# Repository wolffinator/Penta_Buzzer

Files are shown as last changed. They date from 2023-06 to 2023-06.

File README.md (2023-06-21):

# Penta Buzzer
A buzz for the fingers.  
Open source code and assembly for a mobile 4 buzzer hand thingy.  
Purpose of this device is to provide a pre-programmed buzzing pattern to each of the 4 fingers.  
## 💡 Current Features
* Runs program to buzz each finger at set intervals.
* Battery life of over 4hrs while running.
* On/Off button.
* Charge port that also doubles as programming port.
## ⚠️ Word of Warning
* This project is at its infancy. The current hardware design will change and may not work with future versions of this code.
* Project requires intermediate skills in soldering. There are a few surface mount soldering points and many close solder pads. Practice technique if you are unsure.
* ESP32 does not have reverse polarity protection (ask me how I know). Check your work before you fry your board.
* This is not a well designed product (yet). Parts will and have failed. 
### BOM
* [Seeed Studio XIAO ESP32-C3][esp32_c3_link]. This is the microcontroller used in this project. This was chosen due to its built in connectivity and battery management circuitry.  
* [DRV 8833][drv_8833_link]. This is the motor controller which will power each of the 4 buzzers.  
* [MakerFocus 2A 5V Charging Protection Module][makerfocus_charge_discharge_module_link]. This is used to provide 5v for the motors and show current battery capacity. The charging of the battery is accomplished by the microcontroller circuit.
* [9 by 20 by 30mm lithium ion battery][lithium_ion_battery_link] 
* Heat Shrink
* 30AWG stranded wire.
* 22AWG solid core wire.
### 3d Printable Case
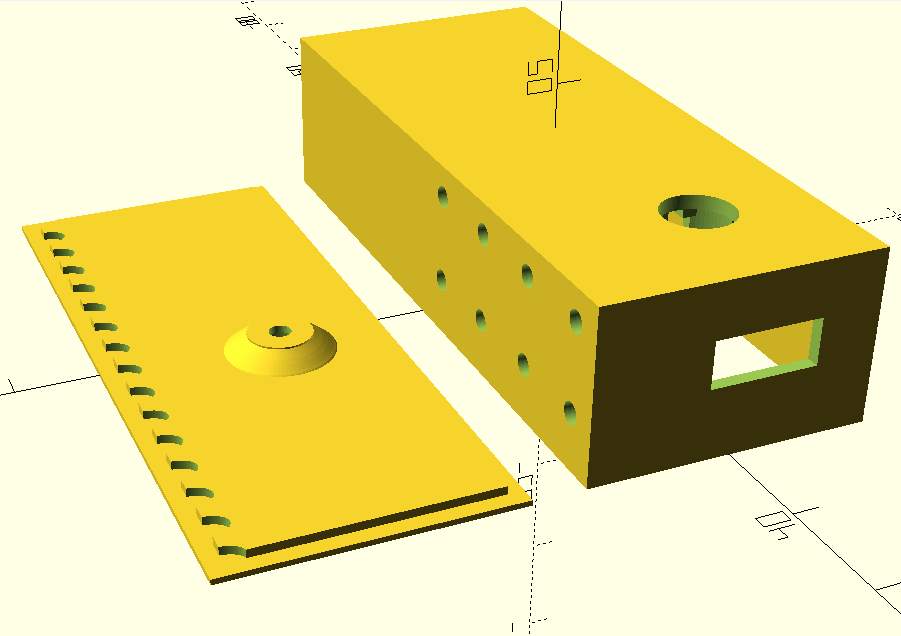
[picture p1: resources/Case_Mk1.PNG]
3d Printable Case

There is an OpenScad document in the Models directory that can be 3d printed as an enclosure for the whole setup. I plan to rework this as it was a pain to assemble.
## 🛠 Flash Firmware (For Users)

## 🛠 Installation Setup (For Developers)
### Install Arduino IDE
### Install Board Support Packages for ESP32
### Install Visual Studio Code (VS-Code)

### Install Platform IO Extension for VS-Code

### Flash Board Firmware

## 🔬 Future plans
### Version 2
* Goal of Version 2 is to see if I can create a PCB that works, is small, and combines many boards into a small footprint.
* Explore fabrication proccess
* Additional goal is for me (wolffinator) to get better at SMD soldering since this will most likely require some rework/repair.
### Version 2 Progress:
#### Schematic
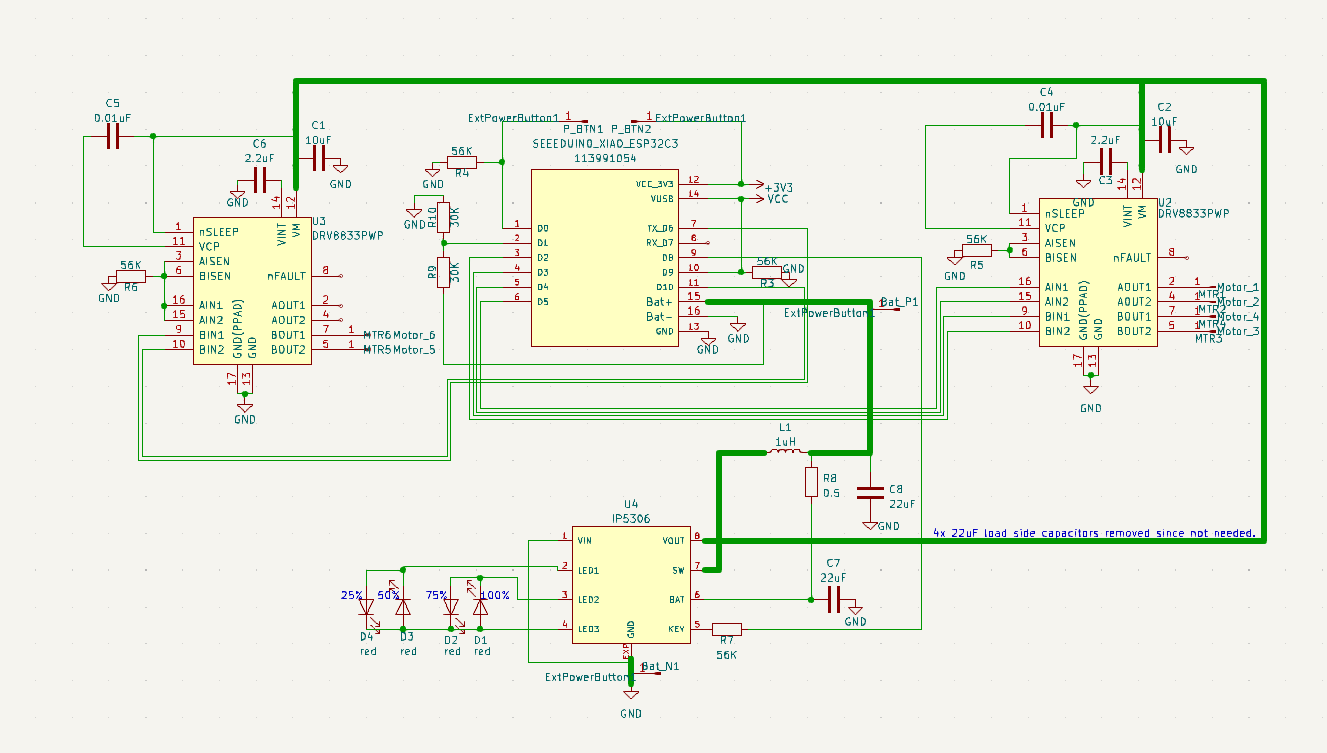
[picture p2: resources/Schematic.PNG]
Schematic

#### PCB Layout
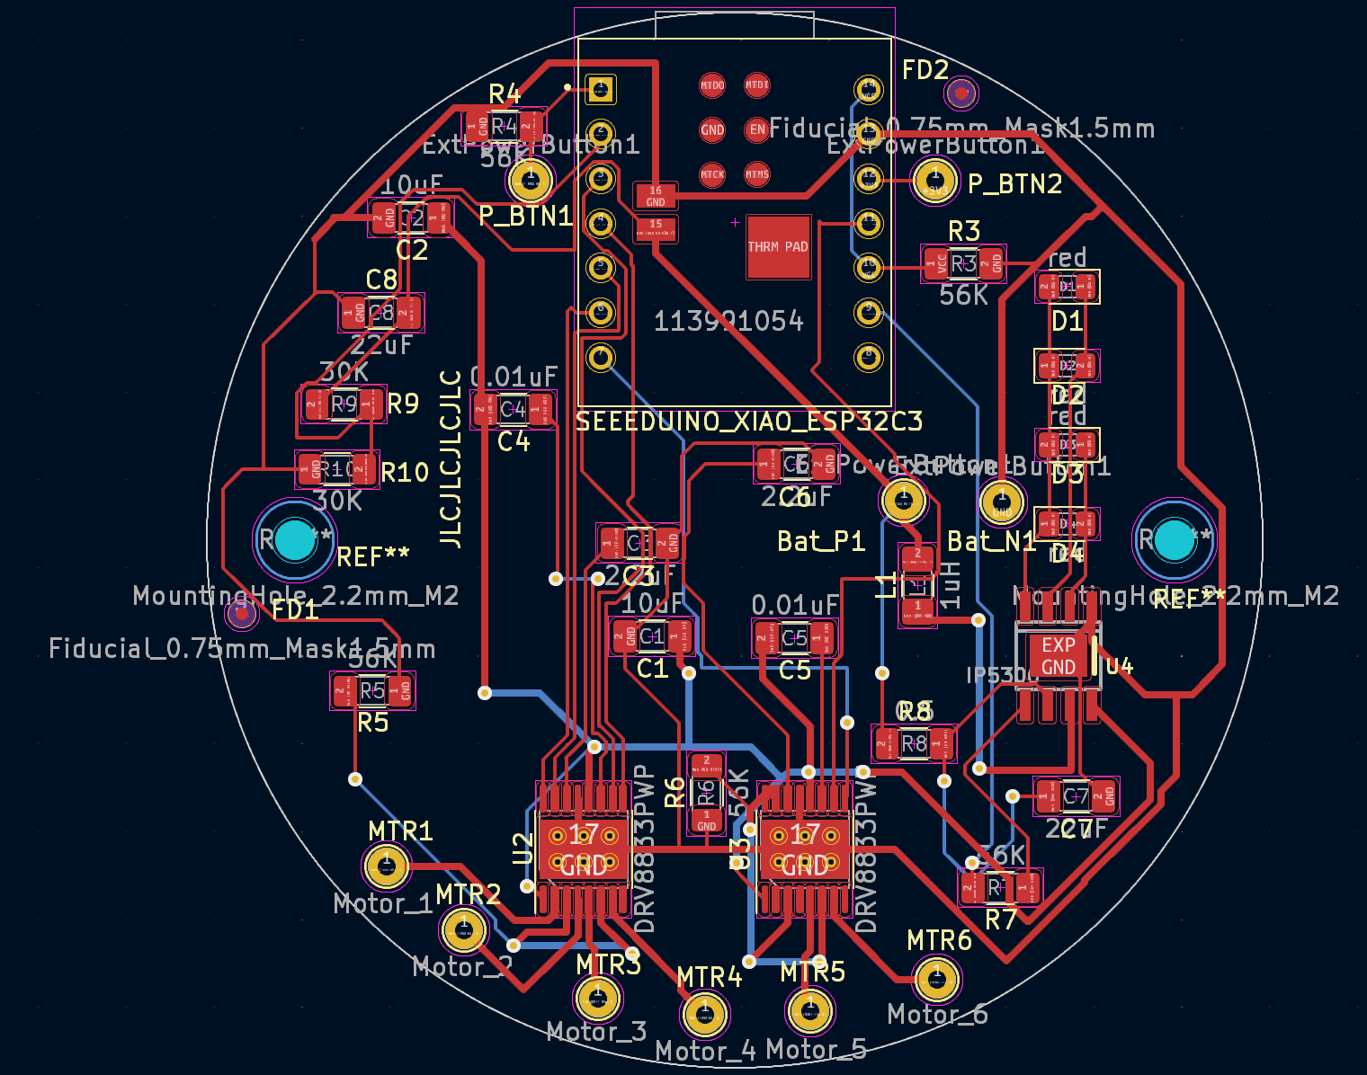
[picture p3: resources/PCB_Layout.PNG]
PCB_Layout

### Version 3
* Goal of Version 3 is to make the design as easy to produce as possible.
* I would love to provide a link for users here to click on and get a quote from one or (or many) PCB manufacturers and have them solder all of the components. It looks like Version 2 requires some hand soldering of SMD components afterwards, which can be difficult.
* Provide a link to a 3d printed case.
* Simplify case assembly and wire soldering as much as possible.
* Include more detailed assembly instructions.

[drv_8833_link]: https://www.amazon.com/gp/product/B0BGLH27GG/ref=sw_img_1?smid=A2QD586WPO9XSR&psc=1
[esp32_c3_link]: https://www.digikey.com/en/products/detail/seeed-technology-co-ltd/113991054/16652880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
[makerfocus_charge_discharge_module_link]: https://www.amazon.com/gp/product/B07PZT3ZW2/ref=ppx_yo_dt_b_search_asin_image?ie=UTF8&psc=1
[lithium_ion_battery_link]: https://www.aliexpress.us/item/3256804370986754.html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

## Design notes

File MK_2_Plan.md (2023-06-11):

# Mark 2 Plans
## Hardware Changes
* Would like to create PCB for ESP32C3 microcontroller to be mounted on, integrate multiple drv 8833 modules into schematic (to add support for all 5 fingers), and integrate 5v power into the schematic (this may not be needed since motors rely on 3v anyways.)
* Update case design and make assembly easier. 
  * Design a better way to secure the Microcontroller and battery without requiring the user to have small fingers.
* Secure connections between buzzer, wire, and control unit.
  * Current running idea is to solder the buzzer to a perf board, then solder larger gauge wire to the perf board.
  * Going to continue idea of adding knot inside control unit box to stop tugging from damaging internal electronics.
## Software Changes
* Wake on detect serial connection and do not go to sleep. Do not buzz any motors unless user does "turn on" action or the board was on before being plugged in.
  * The microcontroller cannot be programmed while sleeping. This new feature should allow programming of the device without the user needing to power it on.

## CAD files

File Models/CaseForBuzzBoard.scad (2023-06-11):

$fa = 1;
$fn=80;

displayTop = 1;


batteryLength = 31;
batteryHeight = 9;
batteryWidth = 20;

batteryDividerThickness = 0.4;

MCUBoardLength = 20;
MCUBoardWidth = 18;
MCUComboBoardHeight = 7.8;

usbPortWidth = 9.5;
usbPortHeight = 3.5;



boardThickness = 1.5;
boardThicknessWiggle = 0.05;
boardLength = 60;
boardWidth = 23;
boardWidthLengthWiggle = 0.5;
outerWallThickness = 1.2;

topWallThickness = 1.32;

buttonCutoutDiameter = 6.45;


buttonHeight = 4.3;
pushButtonHeightFromStopper = 3.5;

pushButtonRodHeight = 1.5;
buttonWiggleRoom = 0.05;
heightFromBoardToBaseofInnerWall = buttonHeight + pushButtonRodHeight + buttonWiggleRoom;
heightFromBoardToBaseofInnerBottomWall = 10;
//heightFromBoardToZBottomOfTop = buttonHeight + pushButtonHeightFromStopper + 0.36 + 5;
heightFromBoardToZBottomOfTop = 14.5;

screwHoleOffsets = 2.5;
screwHoleDiameter = 1.98;
screwHeightFromHead = 5.5;
screwHoleOuterWallThickness = 1.8;


MCUOffCenter = -2.5;

botxyLeftEdge =  [ boardWidth/2, -boardLength/2];
botxyRightEdge = [ boardWidth/2,  boardLength/2];
topxyLeftEdge =  [-boardWidth/2, -boardLength/2];
topxyRightEdge = [-boardWidth/2,  boardLength/2];
button1Pos =     [0 + MCUOffCenter, botxyRightEdge[1]-10];

zTopBoard = boardThickness/2;

batteryFrontY = -(boardLength / 2) + batteryLength;


ribbingSeperation = 4;


bottomWallThickness = 1;
bottomWallThickness2 = 0.5;
bottomWallInsetWiggle = 0.45;



//translate([0,batteryFrontY - (batteryLength/2),batteryHeight/2])
//cube([batteryWidth, batteryLength, batteryHeight], center = true);

//translate([0, boardLength/2 - MCUBoardLength/2,MCUComboBoardHeight/2])
//cube([MCUBoardWidth, MCUBoardLength, MCUComboBoardHeight], center = true);




module batteryDivider(){
    difference(){
        translate([0,batteryFrontY + batteryDividerThickness/2,heightFromBoardToZBottomOfTop/2])
            cube([boardWidth, batteryDividerThickness, heightFromBoardToZBottomOfTop], center = true);
       translate([boardWidth/2 - 15/2,0,0])
            cube([15,20,10], center = true); 
    }
}

module PerfBoard(){
    difference(){
        cube([boardWidth, boardLength, boardThickness], center = true);
        translate([botxyLeftEdge[0] - screwHoleOffsets,botxyLeftEdge[1] + screwHoleOffsets,0])
        cylinder(h=boardThickness*2, d = screwHoleDiameter, center = true);
        translate([botxyRightEdge[0] - screwHoleOffsets,botxyRightEdge[1] - screwHoleOffsets,0])
        cylinder(h=boardThickness*2, d = screwHoleDiameter, center = true);
        translate([topxyLeftEdge[0] + screwHoleOffsets,topxyLeftEdge[1] + screwHoleOffsets,0])
        cylinder(h=boardThickness*2, d = screwHoleDiameter, center = true);
        translate([topxyRightEdge[0] + screwHoleOffsets,topxyRightEdge[1] - screwHoleOffsets,0])
        cylinder(h=boardThickness*2, d = screwHoleDiameter, center = true);
    }
}
module ScrewStandoff(){
    difference(){
        cylinder(h=screwHeightFromHead,d = screwHoleDiameter + screwHoleOuterWallThickness);
        cylinder(h=screwHeightFromHead,d = screwHoleDiameter);
    };
    translate([0,0,screwHeightFromHead])
        cylinder(h=heightFromBoardToZBottomOfTop - screwHeightFromHead-2,d = screwHoleDiameter + screwHoleOuterWallThickness);
}

module PushButtonRotationSetterPair(){
    translate([0,0,-0.5])
    difference(){
        cube([4,9.8,2], center = true);
        cube([1.4,100,100], center = true);
        cube([100,6.5,100], center = true);
    }
}
module PushButtonRotationSetters(){
    rotate([0,0,90])
    difference(){
        rotate([0,0,90])
        PushButtonRotationSetterPair(); 
        translate([50,0,0])
        cube([100,10,10], center = true);
    }
}


module BoardTop(){
    difference(){
        cube([boardWidth, boardLength, topWallThickness], center = true);
        translate([button1Pos[0],button1Pos[1],0])
            cylinder(h = 50, d = 6.45, center = true);
    }
    translate([button1Pos[0],button1Pos[1],0])
        PushButtonRotationSetters();

    
}

module outerWalls()
{
    translate([0,boardLength/2 + outerWallThickness/2,heightFromBoardToZBottomOfTop/2 + topWallThickness/2])
        cube([boardWidth,outerWallThickness,heightFromBoardToZBottomOfTop + topWallThickness], center = true);
    translate([0,-boardLength/2 - outerWallThickness/2,heightFromBoardToZBottomOfTop/2 + topWallThickness/2])
        cube([boardWidth,outerWallThickness,heightFromBoardToZBottomOfTop + topWallThickness], center = true);
    
    translate([-boardWidth/2 - outerWallThickness/2,0,heightFromBoardToZBottomOfTop/2 + topWallThickness/2])
    rotate([0,0,90])
        cube([boardLength + outerWallThickness*2,outerWallThickness,heightFromBoardToZBottomOfTop + topWallThickness], center = true);
    translate([boardWidth/2 + outerWallThickness/2,0,(heightFromBoardToZBottomOfTop/2) + (topWallThickness/2)])
    rotate([0,0,90])
        cube([boardLength + outerWallThickness*2,outerWallThickness,heightFromBoardToZBottomOfTop + topWallThickness], center = true);
    for(i = [-boardLength/2: ribbingSeperation: boardLength/2]){
    translate([boardWidth/2,i,heightFromBoardToZBottomOfTop/2])
    ribbing(heightFromBoardToZBottomOfTop,2);
    }
    
    rotate([0,0,180])
    translate([-boardWidth/2,0,9])
    rotate([90,180,0])
    ribbing(boardLength,2);
}
module ribbing(height, rib_diameter){
difference(){
    cylinder(h=height, d = rib_diameter, center = true);
    translate([rib_diameter/2,0,0])
    cube([rib_diameter,rib_diameter+1,height+1], center = true);
}
}
module CaseTop()
{
    //PerfBoard();
    //translate([botxyLeftEdge[0] - screwHoleOffsets,botxyLeftEdge[1] + screwHoleOffsets,0])
    //    ScrewStandoff();
    translate([0 + MCUOffCenter,batteryFrontY + batteryDividerThickness + screwHoleOuterWallThickness,3])
        ScrewStandoff();
    //translate([topxyLeftEdge[0] + screwHoleOffsets,topxyLeftEdge[1] + screwHoleOffsets,0])
    //    ScrewStandoff();
    //translate([topxyRightEdge[0] + screwHoleOffsets,topxyRightEdge[1] - screwHoleOffsets,0])
    //    ScrewStandoff();
    translate([0,0,heightFromBoardToZBottomOfTop+topWallThickness/2])
        BoardTop();
    //translate([0,0,0])
    //batteryDivider();
    difference(){
        outerWalls();
        translate([0 + MCUOffCenter,40,8.6])
        cube([usbPortWidth+0.2, 40,usbPortHeight+0.8], center = true);
        for(i = [0:1:3]){
            translate([9,4 + i*ribbingSeperation * 2,5])
            rotate([0,90,0])
            cylinder(h=10, d = 2, center = true);
        }
        for(i = [0:1:3]){
            translate([9,4 + i*ribbingSeperation * 2,13])
            rotate([0,90,0])
            cylinder(h=10, d = 2, center = true);
        }
    }

    outerWallPeg = 5.5;
    translate([0 + MCUOffCenter,7,7.5])
    cube([1,4.8,5], center = true);
    translate([14.25-(outerWallPeg/2) + MCUOffCenter,18,7.5])
    rotate([0,0,90])
    cube([1,outerWallPeg,5], center = true);

    //translate([-12.25+(outerWallPeg/2) + MCUOffCenter,18,7.5])
    //rotate([0,0,90])
    //cube([1,outerWallPeg,5], center = true);
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

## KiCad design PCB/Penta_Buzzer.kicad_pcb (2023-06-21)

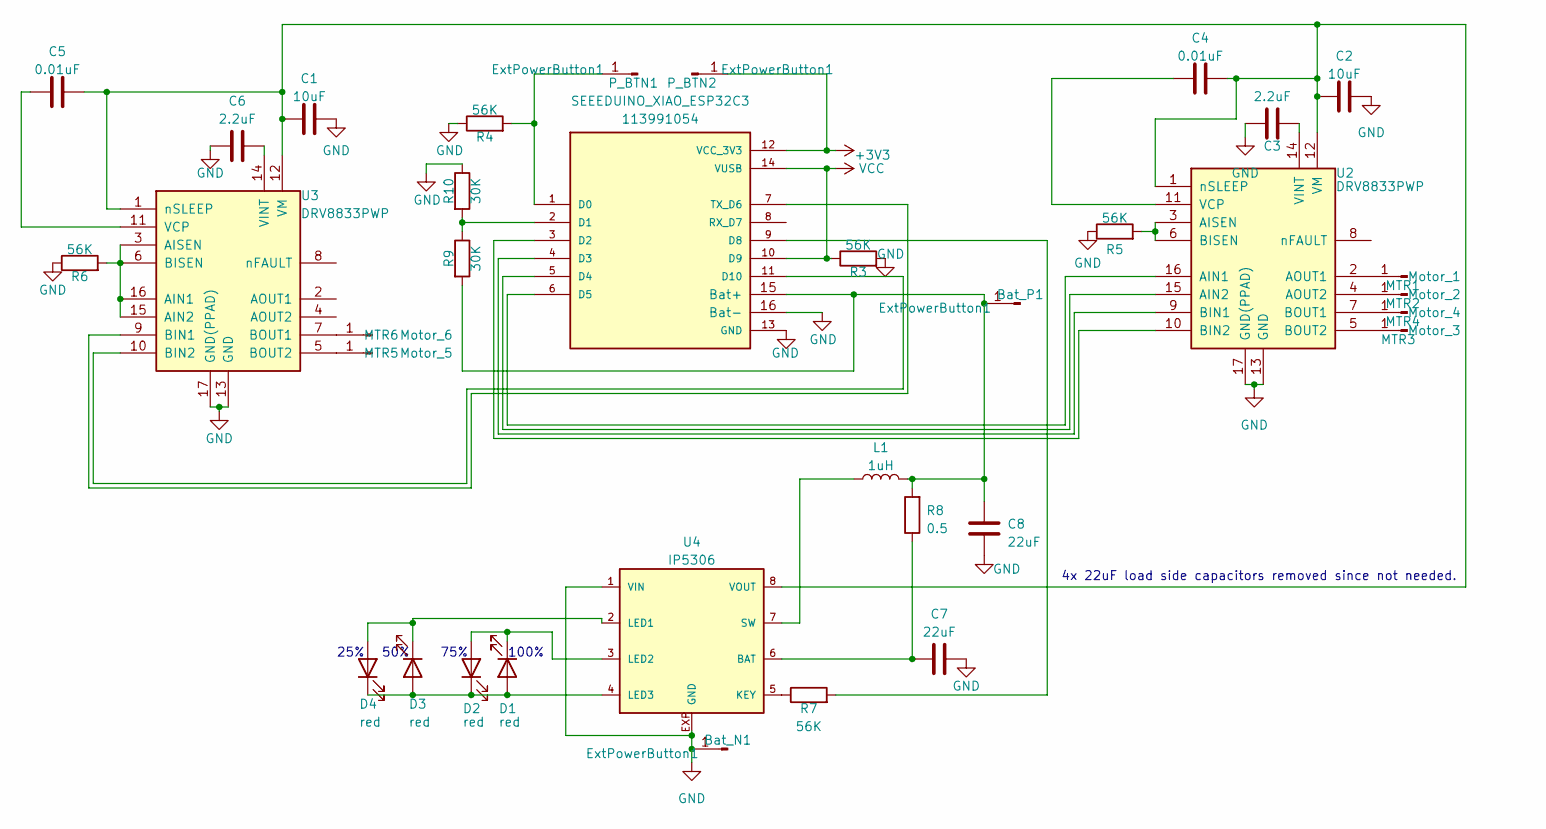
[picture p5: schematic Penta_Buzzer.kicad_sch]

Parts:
Bat_N1: ExtPowerButton1; Pin_D1.0mm_L10.0mm
Bat_P1: ExtPowerButton1; Pin_D1.0mm_L10.0mm
C1, C2: 10uF; C_1206_3216Metric_Pad1.33x1.80mm_HandSolder
C3, C6: 2.2uF; C_1206_3216Metric_Pad1.33x1.80mm_HandSolder
C4, C5: 0.01uF; C_1206_3216Metric_Pad1.33x1.80mm_HandSolder
C7, C8: 22uF; C_1206_3216Metric_Pad1.33x1.80mm_HandSolder
D1, D2, D3, D4: red; LED_0805_2012Metric_Pad1.15x1.40mm_HandSolder
L1: 1uH; L_1206_3216Metric_Pad1.42x1.75mm_HandSolder
MTR1: Motor_1; Pin_D1.0mm_L10.0mm
MTR2: Motor_2; Pin_D1.0mm_L10.0mm
MTR3: Motor_3; Pin_D1.0mm_L10.0mm
MTR4: Motor_4; Pin_D1.0mm_L10.0mm
MTR5: Motor_5; Pin_D1.0mm_L10.0mm
MTR6: Motor_6; Pin_D1.0mm_L10.0mm
P_BTN1, P_BTN2: ExtPowerButton1; Pin_D1.0mm_L10.0mm
R3, R4, R5, R6, R7: 56K; R_1206_3216Metric_Pad1.30x1.75mm_HandSolder
R8: 0.5; R_1206_3216Metric_Pad1.30x1.75mm_HandSolder
R9, R10: 30K; R_1206_3216Metric_Pad1.30x1.75mm_HandSolder
SEEEDUINO_XIAO_ESP32C3: 113991054; MODULE_113991054; PARTREV 23/05/2022
U2, U3: DRV8833PWP; HTSSOP-16-1EP_4.4x5mm_P0.65mm_EP3.4x5mm_Mask2.46x2.31mm_The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
U4: IP5306; SOP8-P

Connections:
+3V3: P_BTN2.1, SEEEDUINO_XIAO_ESP32C3.12 (VCC_3V3)
GND: Bat_N1.1, C1.2, C2.2, C3.2, C6.2, C7.2, C8.1, R3.2, R4.1, R5.1, R6.1, R10.1, SEEEDUINO_XIAO_ESP32C3.13 (GND), SEEEDUINO_XIAO_ESP32C3.16 (Bat-), U2.13 (GND), U2.17 (GND(PPAD)), U3.13 (GND), U3.17 (GND(PPAD)), U4.1 (VIN), U4.EXP (GND)
unnamed: Bat_P1.1, C8.2, L1.2, R8.2, R9.2, SEEEDUINO_XIAO_ESP32C3.15 (Bat+)
unnamed: D1.2 (A), D2.1 (K), D3.2 (A), D4.1 (K), U4.4 (LED3)
unnamed: D1.1 (K), D2.2 (A), U4.3 (LED2)
unnamed: D3.1 (K), D4.2 (A), U4.2 (LED1)
unnamed: MTR1.1, U2.2 (AOUT1)
unnamed: MTR2.1, U2.4 (AOUT2)
unnamed: MTR3.1, U2.5 (BOUT2)
unnamed: MTR4.1, U2.7 (BOUT1)
unnamed: MTR5.1, U3.5 (BOUT2)
unnamed: MTR6.1, U3.7 (BOUT1)
unnamed: P_BTN1.1, R4.2, SEEEDUINO_XIAO_ESP32C3.1 (D0)
unnamed: R9.1, R10.2, SEEEDUINO_XIAO_ESP32C3.2 (D1)
unnamed: SEEEDUINO_XIAO_ESP32C3.3 (D2), U2.10 (BIN2)
unnamed: SEEEDUINO_XIAO_ESP32C3.4 (D3), U2.9 (BIN1)
unnamed: SEEEDUINO_XIAO_ESP32C3.5 (D4), U2.15 (AIN2)
unnamed: SEEEDUINO_XIAO_ESP32C3.6 (D5), U2.16 (AIN1)
unnamed: R7.2, SEEEDUINO_XIAO_ESP32C3.9 (D8)
unnamed: SEEEDUINO_XIAO_ESP32C3.11 (D10), U3.10 (BIN2)
unnamed: SEEEDUINO_XIAO_ESP32C3.7 (TX_D6), U3.9 (BIN1)
unnamed: R5.2, U2.3 (AISEN), U2.6 (BISEN)
unnamed: C4.1, U2.11 (VCP)
unnamed: C3.1, U2.14 (VINT)
unnamed: C1.1, C2.1, C4.2, C5.2, U2.1 (nSLEEP), U2.12 (VM), U3.1 (nSLEEP), U3.12 (VM), U4.8 (VOUT)
unnamed: R6.2, U3.3 (AISEN), U3.6 (BISEN), U3.15 (AIN2), U3.16 (AIN1)
unnamed: C5.1, U3.11 (VCP)
unnamed: C6.1, U3.14 (VINT)
unnamed: C7.1, R8.1, U4.6 (BAT)
unnamed: R7.1, U4.5 (KEY)
unnamed: L1.1, U4.7 (SW)
VCC: R3.1, SEEEDUINO_XIAO_ESP32C3.10 (D9), SEEEDUINO_XIAO_ESP32C3.14 (VUSB)

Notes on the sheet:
75%
100%
4x 22uF load side capacitors removed since not needed.
25%
50%

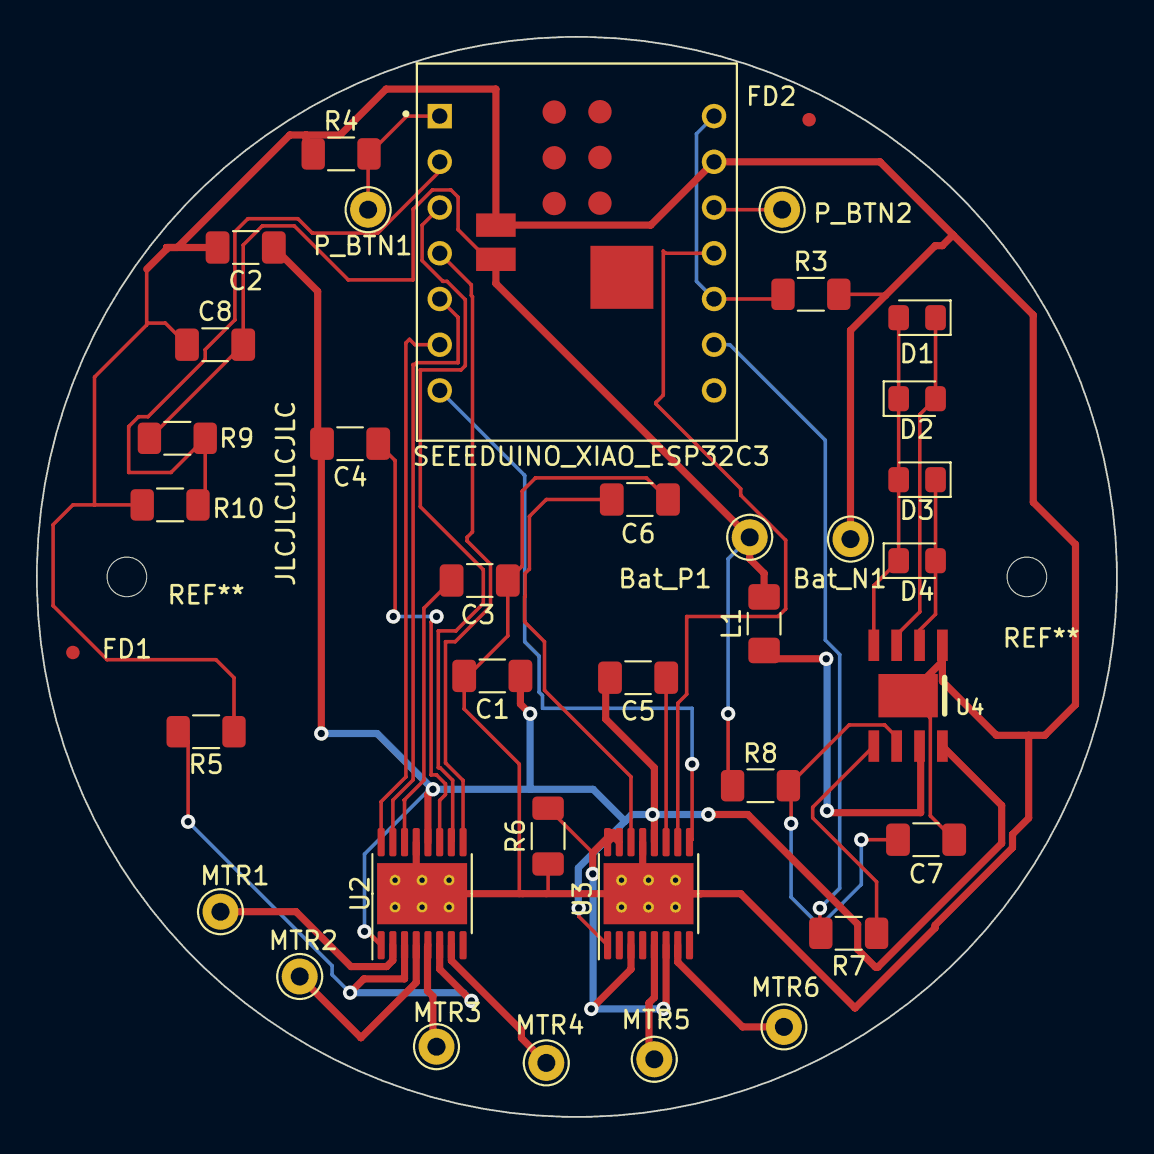
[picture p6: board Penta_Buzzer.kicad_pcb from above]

Board: 2 copper layers, 60.0 x 60.0 mm, 37 parts (0 on the bottom side), 32 nets.

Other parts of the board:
FD1, FD2: Fiducial_0.75mm_Mask1.5mm

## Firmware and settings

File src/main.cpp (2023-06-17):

#include <Arduino.h>
#include "esp_attr.h"
#include "rtc.h"
#include "rtc_store.h"

// GPIO NUMBER IS NOT BOARD OUTPUT NUMBER! See pin_map-2.png
const int MOTOR_1 =                     gpio_num_t::GPIO_NUM_21; // GPIO 21 = PIN D6
const int MOTOR_2 =                     gpio_num_t::GPIO_NUM_7;  // GPIO 7 = PIN D5 as written on board. See pin_map-2.png for more info
const int MOTOR_3 =                     gpio_num_t::GPIO_NUM_4;  // D2
const int MOTOR_4 =                     gpio_num_t::GPIO_NUM_3;  // D1
const int MOTOR_CONTROL_ENABLE_PIN =    gpio_num_t::GPIO_NUM_20; // D7
const int FAULT_PIN =                   gpio_num_t::GPIO_NUM_10; // D10. Is high when board is overheating or over current.
const int POWER_5V_PIN =                gpio_num_t::GPIO_NUM_6;  // D4
const gpio_num_t POWER_BUTTON_PIN_INV = gpio_num_t::GPIO_NUM_2;  // D0. Requires external Pullup
const int USB_DETECT_PIN =              gpio_num_t::GPIO_NUM_8;  // D8 Update to D9 so USB power wakes device. Requires external pulldown
// POWER_BUTTON_PIN will no longer be inverted. External pulldown attached.
// USB_DETECT_PIN updated to pin D9 in V2
// MOTOR_1 updated to pin D5 in V2
// MOTOR_2 updated to pin D4 in V2
// MOTOR_3 updated to pin D3 in V2
// MOTOR_4 updated to pin D2 in V2
// MOTOR_5 updated to pin D6 in V2
// MOTOR_6 updated to pin D10 in V2

enum ButtonState {BUTTON_STATE_OFF, BUTTON_STATE_PUSHED, BUTTON_STATE_ON, BUTTON_STATE_RELEASED};
ButtonState powerButtonState = ButtonState::BUTTON_STATE_OFF;

uint32_t msWhenPowButtonPushed = 0;
uint32_t msNext5vPowerPulse = 5000;

const uint64_t MS_BETWEEN_5V_POWER_PULSES = 10000;
const uint32_t MS_TO_HOLD_BEFORE_POWER_OFF = 2600;
const uint32_t MS_TO_HOLD_BEFORE_POWER_ON = 2600;

uint64_t numTimesMotorControllerFault = 0;

void IRAM_ATTR FaultInterruptHandler();
void IRAM_ATTR OnPowerButtonPushedInterruptHandler();
void CheckStatus();
void Set5VPower(bool powerState);
bool PowerButtonHeldForPowerOn();
void SetupLEDCChannels();
void SetupGPIOs();
void Pulse5VPower(void* parameters);
void PowerOff();
void FakePowerOff();
void PowerOn();
void UpdatePowerButtonState();

//RTC_DATA_ATTR uint64_t mode = 0;
bool isInProgramMode = true;
bool hasButtonBeenReleasedSinceBoot = false;

int timer = 167;           // The higher the number, the slower the timing.

int motorSelections[] = 
{
    4, 1, 2, 3, 1, 4, 2, 3, 1, 2, 4, 3, 13, 13, 13, 13, 13, 13, 13, 13,
    4, 3, 2, 1, 3, 1, 2, 4, 2, 4, 3, 1, 13, 13, 13, 13, 13, 13, 13, 13,
    3, 4, 1, 2, 1, 3, 2, 4, 2, 1, 4, 3, 13, 13, 13, 13, 13, 13, 13, 13,
    3, 4, 2, 1, 4, 3, 1, 2, 1, 4, 3, 2, 13, 13, 13, 13, 13, 13, 13, 13,
    2, 3, 1, 4, 1, 3, 4, 2, 1, 2, 3, 4, 13, 13, 13, 13, 13, 13, 13, 13,
    4, 2, 3, 1, 3, 2, 1, 4, 2, 1, 3, 4, 13, 13, 13, 13, 13, 13, 13, 13,
    3, 1, 4, 2, 4, 2, 1, 3, 2, 3, 4, 1, 13, 13, 13, 13, 13, 13, 13, 13,
    4, 1, 3, 2, 3, 2, 4, 1, 2, 4, 1, 3, 13, 13, 13, 13, 13, 13, 13, 13
};
// an array of pin numbers to which LEDs are attached Pin 13 is a pause
const int pinCount = sizeof(motorSelections) / sizeof(int);           // the number of pins (i.e. the length of the array)
int motorSelectionIdx = 0;

const int PWM_FREQ = 5000;
const int LEDC_CHANNEL1 = 0;
const int LEDC_CHANNEL2 = 1;
const int LEDC_CHANNEL3 = 2;
const int LEDC_CHANNEL4 = 3;
const int PWM_RES = 8;// PWM values of 0-255 are valid with 8 bits of resolution

/// @brief Generally speaking, the first function called by arduino.
void setup() {
    hasButtonBeenReleasedSinceBoot = false;
    SetupGPIOs();
    
    if(!PowerButtonHeldForPowerOn())// Waits here for MS_TO_HOLD_BEFORE_POWER_ON milliseconds or less before continueing
    {
        PowerOff();// Does not return
    }
    PowerOn();
    msNext5vPowerPulse = millis() + MS_BETWEEN_5V_POWER_PULSES;
    delay(10);// Give time for 5v to power up.
}

/// @brief Setup up GPIOs as inputs or outputs and attach interrupts.
void SetupGPIOs()
{
    pinMode(POWER_5V_PIN, OUTPUT);
    digitalWrite(POWER_5V_PIN, HIGH);
    pinMode(MOTOR_CONTROL_ENABLE_PIN, OUTPUT);

    SetupLEDCChannels();

    pinMode(FAULT_PIN, INPUT + PULLUP);
    attachInterrupt(FAULT_PIN, FaultInterruptHandler, FALLING);// If pin goes low, then motor driver has a fault and run this function.
    
    pinMode(POWER_BUTTON_PIN_INV, INPUT);
    gpio_pullup_en(POWER_BUTTON_PIN_INV);
    attachInterrupt(POWER_BUTTON_PIN_INV, OnPowerButtonPushedInterruptHandler, FALLING);
}

/// @brief Setup LEDC channels. These are used to generate PWM signals for motors.
void SetupLEDCChannels()
{
    ledcSetup(LEDC_CHANNEL1, PWM_FREQ, PWM_RES);
    ledcSetup(LEDC_CHANNEL2, PWM_FREQ, PWM_RES);
    ledcSetup(LEDC_CHANNEL3, PWM_FREQ, PWM_RES);
    ledcSetup(LEDC_CHANNEL4, PWM_FREQ, PWM_RES);
    // attach the channel to the GPIO to be controlled
    ledcAttachPin(MOTOR_1, LEDC_CHANNEL1);
    ledcAttachPin(MOTOR_2, LEDC_CHANNEL2);
    ledcAttachPin(MOTOR_3, LEDC_CHANNEL3);
    ledcAttachPin(MOTOR_4, LEDC_CHANNEL4);
}

/// @brief Main loop of arduino. This function gets called forever.
void loop() {
    static bool isFirstTime = true;
    if(isFirstTime)
    {
        vTaskPrioritySet(NULL, tskIDLE_PRIORITY + 2);
        isFirstTime = false;
    }
    CheckStatus();
    switch (motorSelections[motorSelectionIdx])
    { 
        case 1:
            ledcWrite(LEDC_CHANNEL1, 153); 
            delay(timer);
            ledcWrite(LEDC_CHANNEL1, 0);
        break;
        case 2:
            ledcWrite(LEDC_CHANNEL2, 153);
            delay(timer);
            ledcWrite(LEDC_CHANNEL2, 0);
        break;
        case 3:
            ledcWrite(LEDC_CHANNEL3, 153); 
            delay(timer);
            ledcWrite(LEDC_CHANNEL3, 0);
        break;
        case 4:
            ledcWrite(LEDC_CHANNEL4, 153); 
            delay(timer);
            ledcWrite(LEDC_CHANNEL4, 0);
        break;
        case 13:
            delay(timer);
        break;
    }
    motorSelectionIdx = (motorSelectionIdx + 1) % pinCount;
}

/// @brief Check current power button state and do any interactions associated with that state.
void UpdatePowerButtonState()
{
    if(powerButtonState == ButtonState::BUTTON_STATE_ON)
    {
    }
    else if(powerButtonState == ButtonState::BUTTON_STATE_OFF)
    {
        hasButtonBeenReleasedSinceBoot = true;
    }
    else if(powerButtonState == BUTTON_STATE_PUSHED)
    {
        msWhenPowButtonPushed = millis();
        powerButtonState = ButtonState::BUTTON_STATE_ON;
    }
    else if(powerButtonState == BUTTON_STATE_RELEASED)
    {
        powerButtonState = ButtonState::BUTTON_STATE_OFF;
    }
}

/// @brief Checks status of buttons and runs 5v power pulses. Turns off microcontroller if requirements met.
void CheckStatus()
{
    UpdatePowerButtonState();
    if(((millis() - msWhenPowButtonPushed) > MS_TO_HOLD_BEFORE_POWER_OFF) && (powerButtonState != ButtonState::BUTTON_STATE_OFF && powerButtonState != BUTTON_STATE_RELEASED) && hasButtonBeenReleasedSinceBoot)
    {
        PowerOff();// Does not return
    }
    if(millis() > msNext5vPowerPulse && powerButtonState != ButtonState::BUTTON_STATE_ON && powerButtonState != ButtonState::BUTTON_STATE_PUSHED)
    {
        msNext5vPowerPulse += MS_BETWEEN_5V_POWER_PULSES;
        xTaskCreate(Pulse5VPower, "Pulse5VPower", 6000, NULL, tskIDLE_PRIORITY + 1, NULL);// Create non-blocking task to keep power on.
    }
    powerButtonState = digitalRead(POWER_BUTTON_PIN_INV)? ButtonState::BUTTON_STATE_OFF : ButtonState::BUTTON_STATE_ON;
}

/// @brief One-shot ISR for when motor controller produces a fault. 
/// This can happen because either the motor controller is overheating or the current limit has been exceeded.
/// IRAM_ATTR used to keep function in RAM.
void IRAM_ATTR FaultInterruptHandler()
{
    numTimesMotorControllerFault += 1;
}

/// @brief One-shot ISR for when power button pushed down.
/// IRAM_ATTR used to keep function in RAM.
void IRAM_ATTR OnPowerButtonPushedInterruptHandler()
{
    powerButtonState = BUTTON_STATE_PUSHED;
}

/// @brief If usb plugged in, don't go to sleep. Just wait for user to power on device and restart on button push.
void FakePowerOff()
{
    while(digitalRead(POWER_BUTTON_PIN_INV)){delay(10);}
    esp_restart();
}

/// @brief This function will not return unless plugged into USB.
void PowerOff()
{
    digitalWrite(MOTOR_CONTROL_ENABLE_PIN, false); // Turn off Motor Controller.
    Set5VPower(false); // Turn off 5v supply for motors.
    if(!digitalRead(USB_DETECT_PIN)) // If USB not plugged in.
    {
        esp_deep_sleep_enable_gpio_wakeup(1 << uint64_t(POWER_BUTTON_PIN_INV), esp_deepsleep_gpio_wake_up_mode_t::ESP_GPIO_WAKEUP_GPIO_LOW);
        while(!digitalRead(POWER_BUTTON_PIN_INV));// Wait until button released
        esp_deep_sleep_start(); // Go into deep sleep. Will only wake on power button being pushed.
    }
    else 
    {
        FakePowerOff();
    }
    return;
}

/// @brief Power on motor controller and 5v power rail.
void PowerOn()
{
    digitalWrite(MOTOR_CONTROL_ENABLE_PIN, true); // Turn on Motor Controller.
    Set5VPower(true); // Turn on 5v supply for motors.
}

/// @brief Task to pulse the 5v power "on" signal. Must be done within every 30 seconds.
/// @param parameters 
void Pulse5VPower(void* parameters)
{
    Set5VPower(true);
    vTaskDelete(NULL);
}

/// @brief Sets 5v power rail to on or off state. Blocks for up to 1.5 seconds.
/// @param powerState true for 5v on. false for off.
void Set5VPower(bool powerState)
{
    if(powerState)
    {
        // Serial.println("Pulsing 5v power on");
        digitalWrite(POWER_5V_PIN, LOW);
        delay(400);
        digitalWrite(POWER_5V_PIN, HIGH);
    }
    else
    {
        // Serial.println("Pulsing 5v power off");
        digitalWrite(POWER_5V_PIN, LOW);
        delay(400);
        digitalWrite(POWER_5V_PIN, HIGH);
        delay(400);
        digitalWrite(POWER_5V_PIN, LOW);
        delay(400);
        digitalWrite(POWER_5V_PIN, HIGH);
    }
}

/// @brief Blocks and checks if user has held the power button for "MS_TO_HOLD_BEFORE_POWER_ON" ms.
/// @return Returns true if power button held for enough time. false if button was held for any shorter or not pressed at all.
bool PowerButtonHeldForPowerOn()
{
    while((millis() - msWhenPowButtonPushed) <= MS_TO_HOLD_BEFORE_POWER_ON)
    {
        if(digitalRead(POWER_BUTTON_PIN_INV))// If button released early
        {
            powerButtonState = ButtonState::BUTTON_STATE_OFF;
            return false;
        }
        powerButtonState = ButtonState::BUTTON_STATE_ON;
        delay(50);
    }
    msWhenPowButtonPushed = INT_MAX;
    return true;
}

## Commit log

2023-06-11 Adding mk1 model and more documentation
    [CaseForBuzzBoard.scad]
2023-06-11 More documentation
    [CaseForBuzzBoard.scad]
2023-06-17 Schematic for V2 first commit
    [Penta_Buzzer.kicad_pcb, Penta_Buzzer.kicad_sch]
2023-06-21 Gitignore and more updates to schematic
    [Penta_Buzzer.kicad_pcb, Penta_Buzzer.kicad_sch]
